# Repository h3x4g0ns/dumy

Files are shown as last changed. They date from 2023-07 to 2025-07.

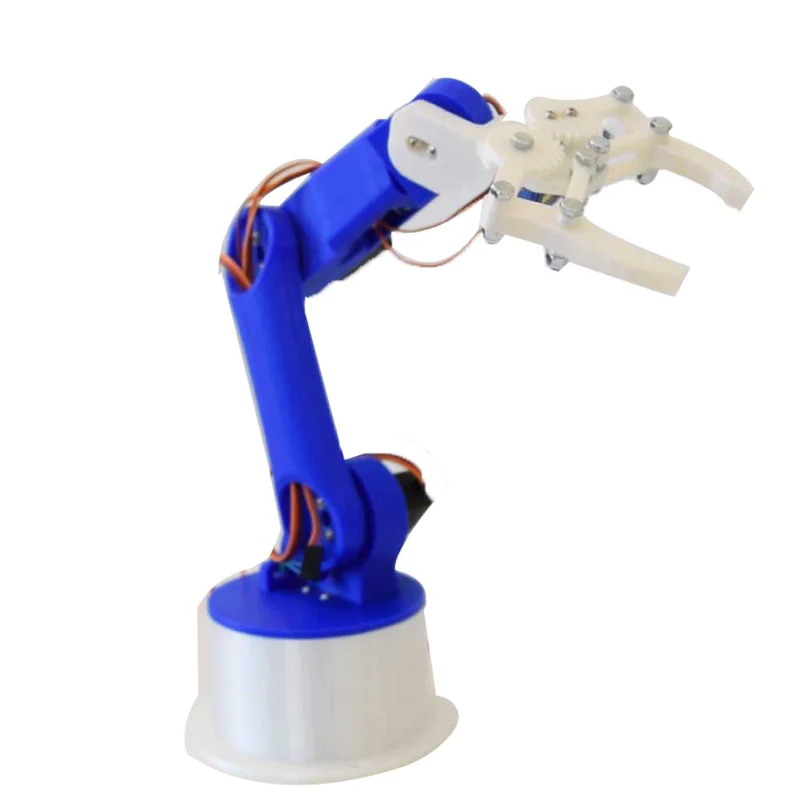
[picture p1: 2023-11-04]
robot_arm.webp

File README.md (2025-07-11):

# dumy

Control a 3/4 DOF robot arm to track a cat and constantly play laser pointer fetch with her

## design

- We will have the server code running on a Jetson that will capture the environment through a camera
- We want to perform our computations given the environment to control the world coordinates of the robot
- We will then want to pass in the new joint angles into a serial port on the RP2040 which is connected to the laser pointer arm
- This will move the robot arm accordingly so it's always stimulating the cat

**Vision Stack**

- We want to be able to track a bounding box over the moving cat
  - Use something like PyTorch YOLOv5 to get bounding box over entity identified as cat
    - We can use the center point of the cat
    - OR we can find point on bounding box closest to the laser pointer
- We want to constantly move the laser pointer such that it's moving away from the cat
- If we detect that cat has stopped chasing it, we should taunt the cat by moving the pointer in front of cat
- We can use the trajectory of the cat as a hueristic to determine where the cat will be headed

**Control Stack**

- We need calculate the world coordinate of the robot
  - Given goal coordinates we can solve analytical inverse kinematics to ascertain joint angles
- Pass in joint angles to RP2040 for control through serial communication
  - Server code runs on jetson and will connect to RP2040

## setup

First installing pico sdk.

```sh
cd ~
git clone -b master https://github.com/raspberrypi/pico-sdk.git
cd pico-sdk
git submodule update --init
```

Add following line to `.bashrc` or `.zshrc`.

```sh
export PICO_SDK=~/pico-sdk
```

Install toolchain for Pico projects

```sh
# DEBIAN
sudo apt update
sudo apt install cmake gcc-arm-none-eabi build-essential

# MACOS
# Install cmake
brew install cmake

# Install the arm eabi toolchain
brew tap ArmMbed/homebrew-formulae
brew install arm-none-eabi-gcc

# The equivalent to build-essential on linux, you probably already have this.
xcode-select --install
```

## notes

MiDaS Model: v3.0 DPTL-384
dpt_large_384

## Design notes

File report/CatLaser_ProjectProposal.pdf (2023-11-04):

Project Title: Dumy
Team: Ekansh Parag Agrawal , Anirudh Singh Chaudhary , Jayden Hilton EECS 149/249A Project Charter, Fall, 2023 Repo Link: h3x4g0ns/dumy (https://github.com/h3x4g0ns/dumy)

Project Goal:
The goal of the project is to automate playing a game of laser-fetch with a cat. We will utilize a 3-DOF robot arm with an attached laser. The computations will be done either by a headless Linux server computer or by an NVIDIA Jetson board.

Project Approach:
We will have the server code running on a [Jetson or Headless Linux server] that will process camera frames using a YOLOv5 model and monocular depth detection.With the monocular depth estimation we can use transformations to create a limited 3d world view. From the bounding box of the cat along with the calculated world position of the laser tip, we will then try and correct the position of the arm to the trajectory of the cat. We will solve an analytical inverse kinematic problem to understand where the robot arm must move in order to keep the laser pointer out of the cat’s reach. We will then want to pass in the new joint angles to the RP2040 through a serial connection from the Jetson. The RP2040 will then move the arm to the necessary world position from the joint angles. This will move the robot arm accordingly so it's always stimulating the cat.

Materials:
- RP2040
- NVIDIA Jetson
- 3d printed robot arm
- Headless Linux Server
- Laser pointer
- Servo motors
- Breadboard
- Jumper Cables
- Power Supply

Schedule:
Oct 23, 2023 : Complete Project Proposal
Nov 7, 2023: Milestone 1 Due
Hardware: Design, manufacture, and assembly robot arm
Robot Stack: Basic robot controls, being able to move and control the robot arm to go in the desired direction & orientation [Jaden]
Vision Stack: Be able to identify the cat and begin calculations for world position of the laser tip [Ekansh & Anirudh]
Nov 8-10, 2023: Milestone 1 Presentations
Nov TBD, 2023: Milestone 2 Due

This is more of the integration milestone where we should be able to move the robot arm to follow the cat. From there if we can do that then we will be able to move the laser pointer away from the cat as well. [Everyone together]
Nov - Dec, 2023: Milestone 2 Meetings
December 13, 2023: Project Demo/Poster
December 14, 2023: Peer Evals and Project Report Due

Risk and Feasibility:

Risks:
- Optimizing computer vision/latencies
- Possible hardware failures with servos and 3d printed parts.
- Stretch goals may not be feasible in allotted time
- When dealing with image <-> camera <-> world transformation there’s a lot of trial and error that goes into calibrations, projections, and transformations

Feasibility:
We believe that the project is entirely feasible, most of the resources required are already in hand, and the boilerplate code is in progress. The most obvious risks are with the vision stack, as that comprises most of the risk. There is no physical risk except for an uncontrolled robot swing but we will take necessary precautions to make sure that we are a safe distance away when dealing with the robot arm.

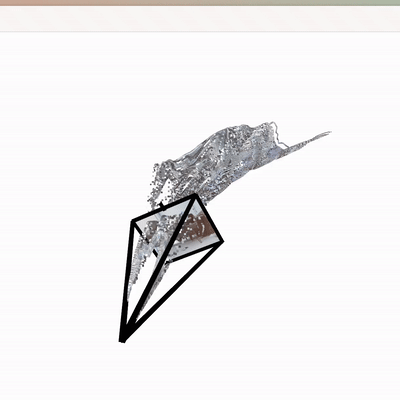
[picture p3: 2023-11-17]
report/voxel_view.gif

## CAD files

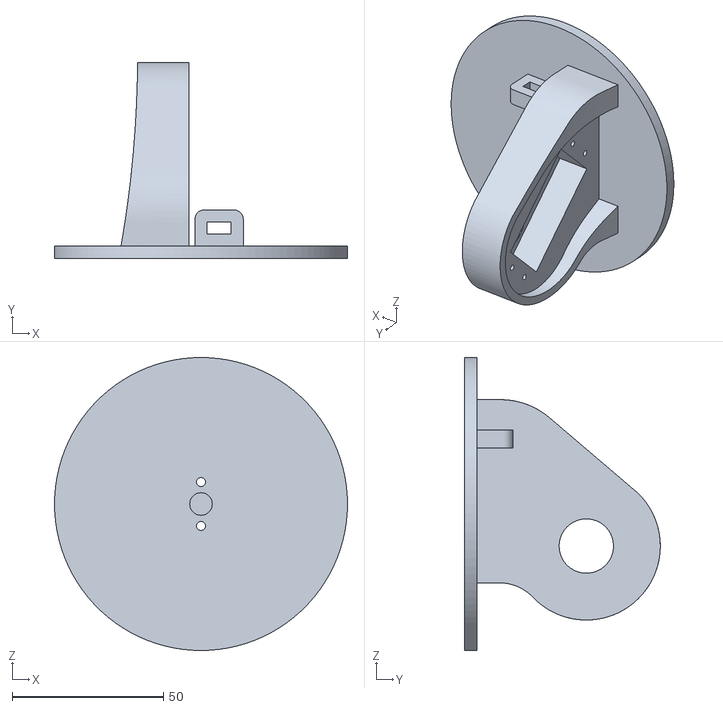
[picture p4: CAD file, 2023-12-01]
stl/Adjusted_WaistJoint.stl
97.0 x 64.8 x 97.0

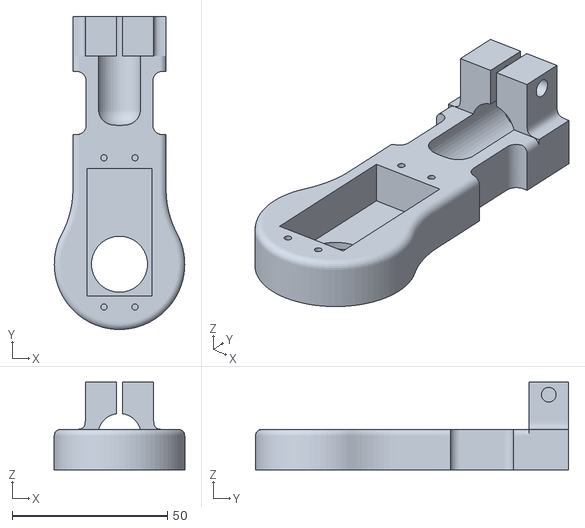
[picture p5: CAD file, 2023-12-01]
stl/Lightweight_Arm2_LaserClamp_v3.stl
42.0 x 100.7 x 28.2

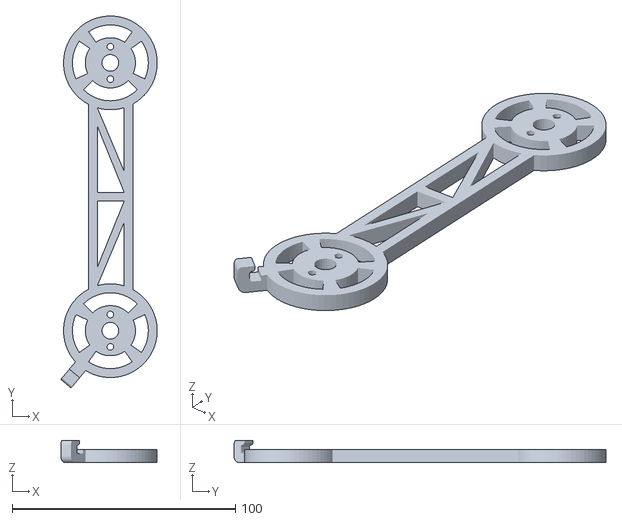
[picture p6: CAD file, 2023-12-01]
stl/Lightweight_Arm1.stl
43.2 x 166.7 x 10.0

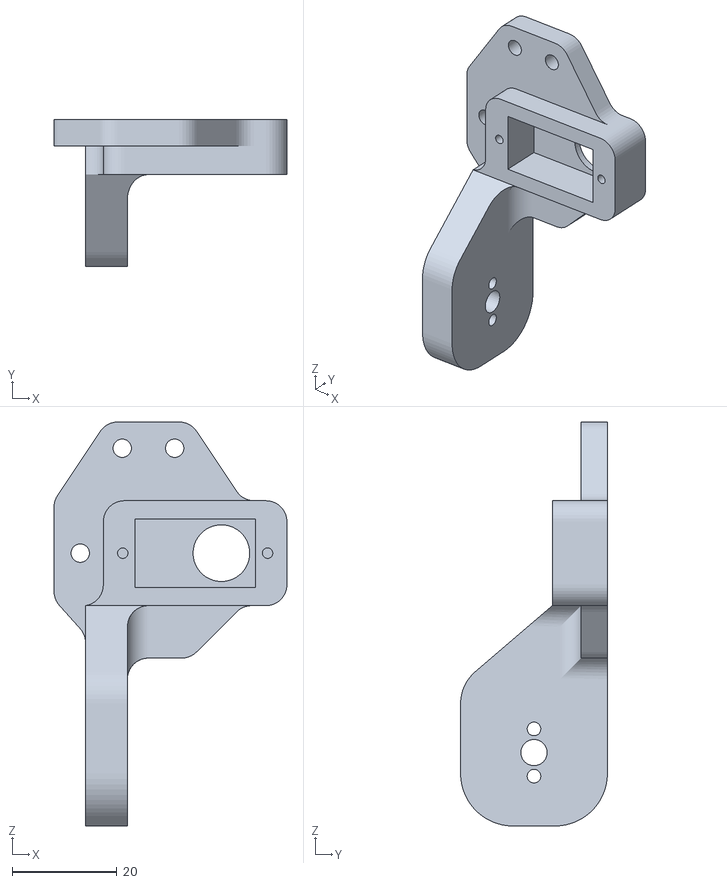
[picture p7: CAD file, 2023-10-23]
stl/Gripper base.stl
44.4 x 28.0 x 77.0

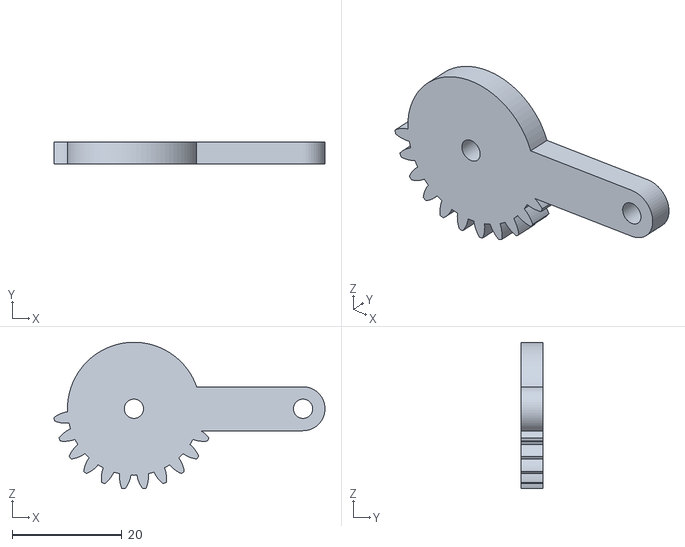
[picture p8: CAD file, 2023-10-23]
stl/gear1.stl
49.3 x 4.00 x 26.6

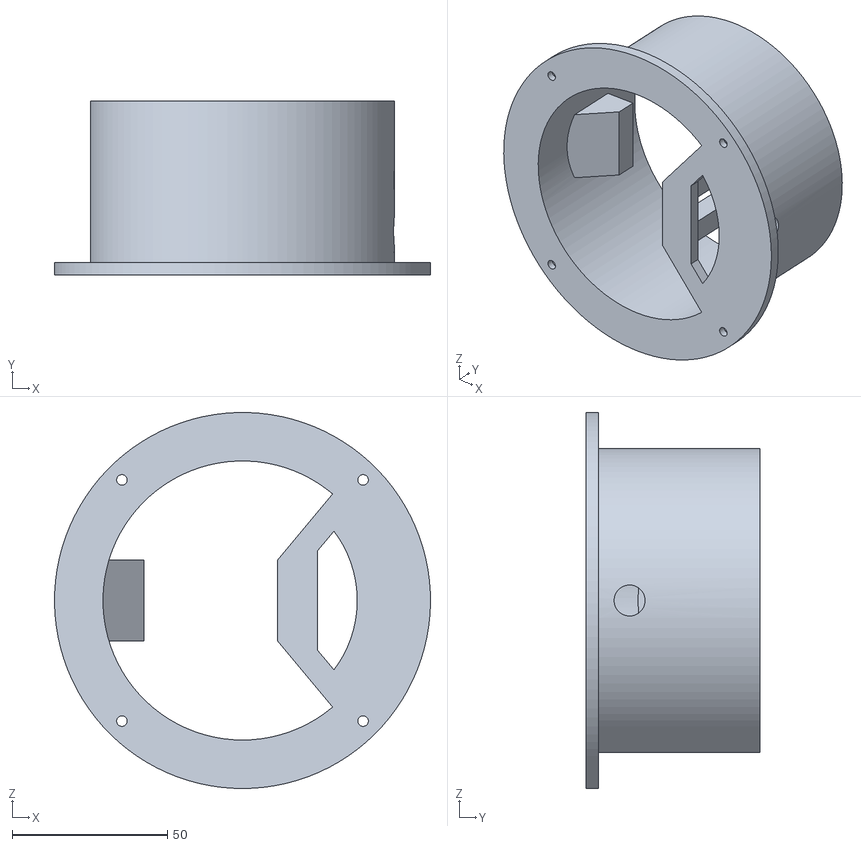
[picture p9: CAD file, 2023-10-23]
stl/Base.stl
121.2 x 56.0 x 121.2

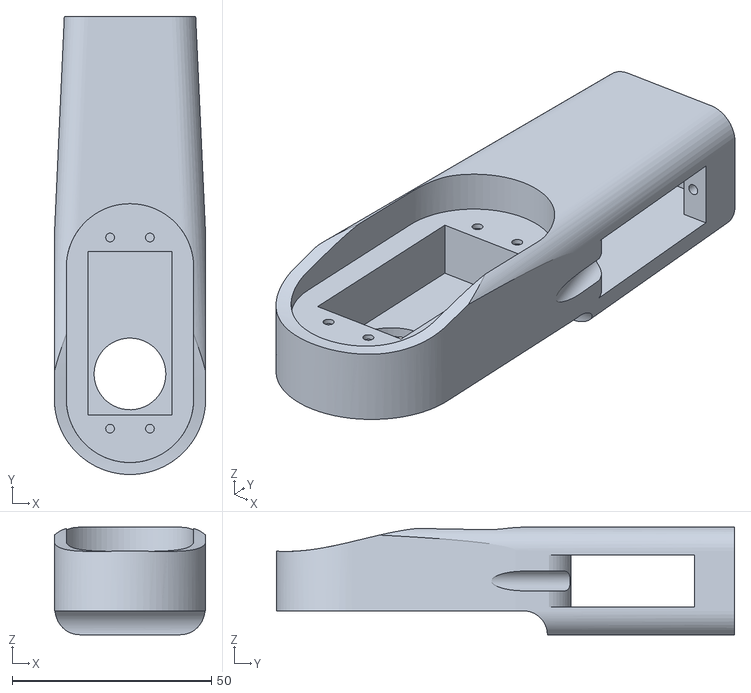
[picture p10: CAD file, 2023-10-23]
stl/Arm 02 v3.stl
38.0 x 115.0 x 27.0

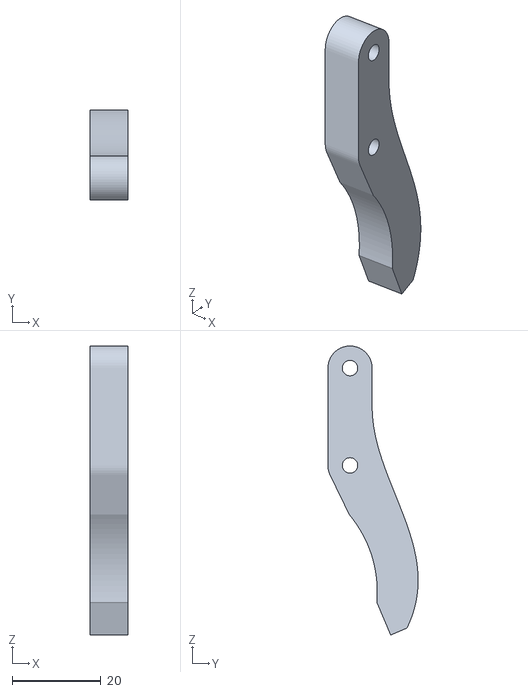
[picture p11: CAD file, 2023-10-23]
stl/Gripper 1.stl
8.50 x 20.4 x 65.3

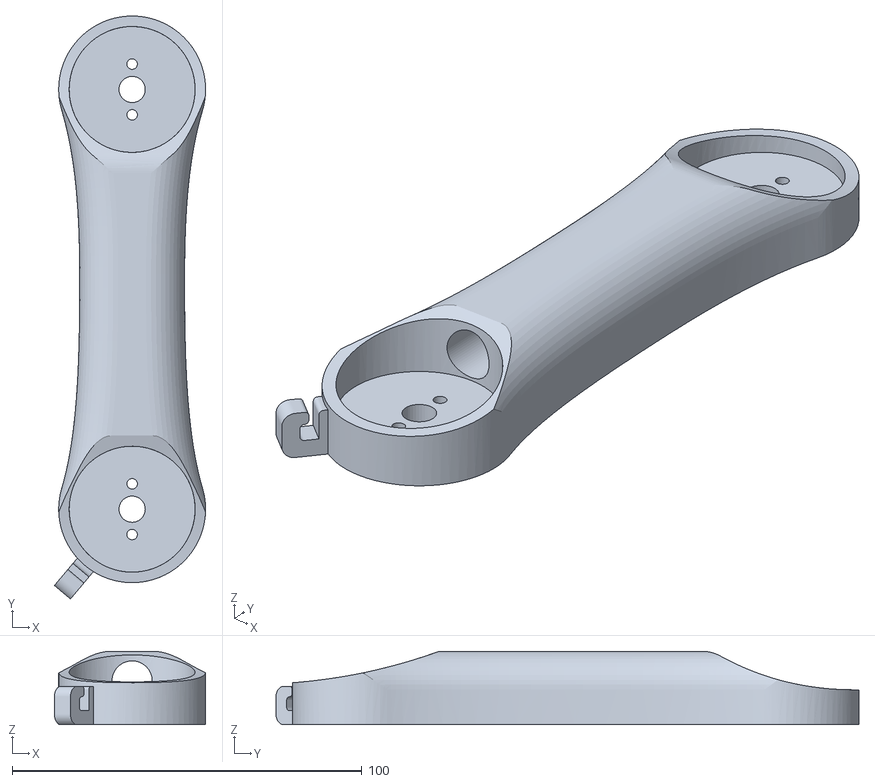
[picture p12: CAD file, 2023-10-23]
stl/Arm 01.stl
43.2 x 166.7 x 21.0

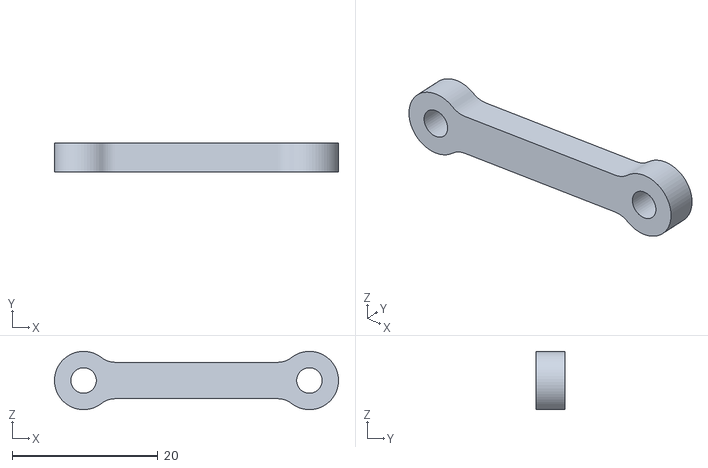
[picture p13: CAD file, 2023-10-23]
stl/grip link 1.stl
39.0 x 4.00 x 8.00

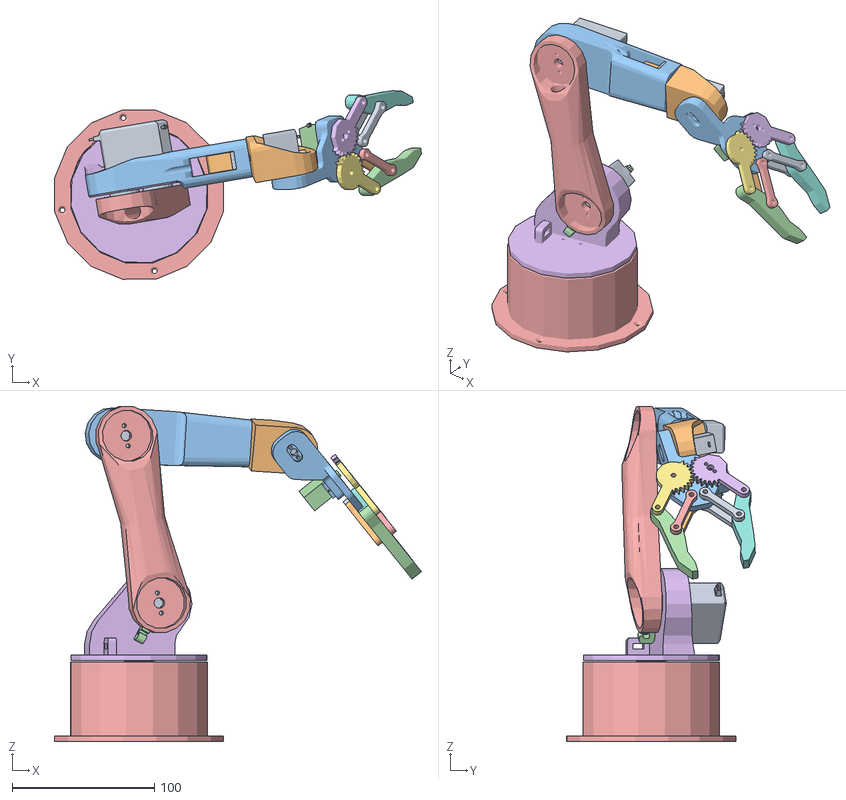
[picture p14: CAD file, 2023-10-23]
stl/Robotic Arm 3D Model.stl
258.2 x 132.6 x 235.7
Boss-Extrude2 x 2
Cut-Extrude2 x 4
Cut-Extrude1 x 4
Boss-Extrude5 x 3
Boss-Extrude7[1] x 3
Boss-Extrude7[2] x 3
Boss-Extrude7[3] x 3
Boss-Extrude12[1] x 3
Boss-Extrude12[2] x 3
Boss-Extrude12[3] x 3
Cut-Extrude7
Cut-Extrude17
CSK#for#M3#Countersunk#Flat#Head#Screw1

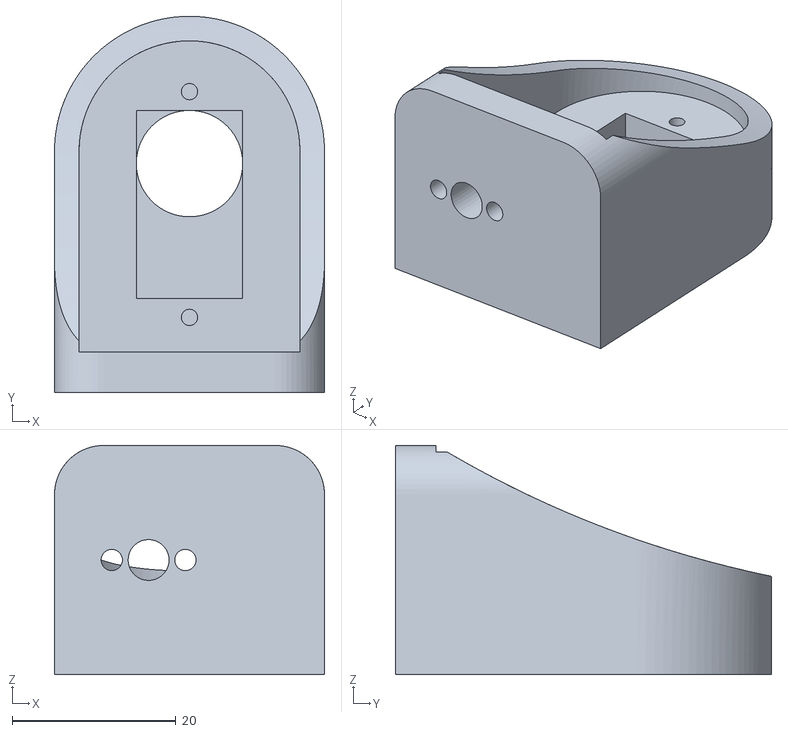
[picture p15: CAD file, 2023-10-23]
stl/Arm 03.stl
33.0 x 46.0 x 28.0

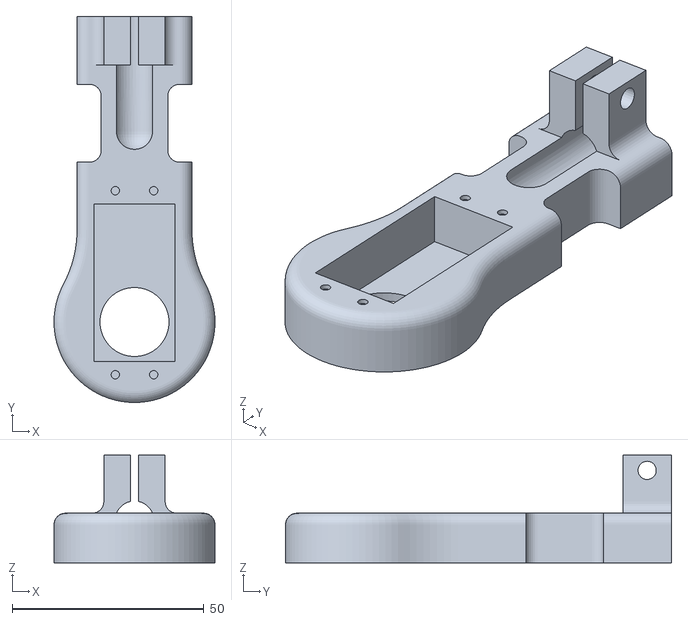
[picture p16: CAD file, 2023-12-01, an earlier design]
stl/Lightweight_Arm2_LaserClamp.stl
42.0 x 100.7 x 28.2

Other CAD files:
stl/Waist.stl
stl/gear2.stl
stl/Lightweight_Arm2_LaserClamp_v2.stl

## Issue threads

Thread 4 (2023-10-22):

depth to world

h3x4g0ns, 2023-10-22:
Now that we have the depth output from the world, we need to use it a heuristic to construct a 3d world view. This should be relatively trivial since the depth is returned as a float from the matrix. Think about this as lidar reconstruction with monocular depth estimation. Look at some of Anjoo;s work with Nerfs, although i doubt we will need anything as complicated as that. I will be completely honest I don't think this has to be extremely accurate so feel free to use whatever transformation mechanism you want.

TODO:
- [ ] make a `camera.py` file in the `lib` folder and write the starter code there

h3x4g0ns, 2023-11-18:
#7 finished

Closed 2023-11-18.

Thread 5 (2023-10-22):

serial controller for dumy

h3x4g0ns, 2023-10-22:
We want to be able to send joint angles from the IK that was solved in `lib/robot.py`. As a refresher, we pass in world coordinates and determine the required joint angles to allow the actuators to reach that world coordinate. Implementations should involve controlling servos on Dumy through MicroPython or Arduino.

TODO
- [ ] validate that IK works from robot
- [ ] send and read serial communication
- [ ] translate joint angles into corresponding PWM signals
- [ ] see if we need a homing mechanism since it's unclear if the servos have encoders

Closed 2023-12-01.

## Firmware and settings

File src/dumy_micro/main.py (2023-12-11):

import _thread
from machine import Pin, UART, Servo, PWM
import time

# Constants
L1_PORT = 10
L2_PORT = 11
L3_PORT = 12
PIEZO_PIN = 13  # TODO: Replace with the actual pin number for the piezo buzzer
OFFSET = 90

# Global variables
piezo_flag = False
piezo_lock = _thread.allocate_lock()  # Create a lock for the piezo_flag variable

# Initialize Servo objects
l1 = Servo(Pin(L1_PORT))
l2 = Servo(Pin(L2_PORT))
l3 = Servo(Pin(L3_PORT))
piezo = PWM(Pin(PIEZO_PIN))

# Function to parse into from serial in
def to_int(src, size):
    try:
        return int(src[:size])
    except ValueError:
        return 0

# Servo control function
def servo_control():
    # Setup UART for serial communication
    uart = UART(1, baudrate=9600)

    terminated = False
    data = bytearray(16)
    i = 0

    while True:
        if uart.any():
            incoming = uart.read(1)
            if incoming == b'r':
                terminated = True
                i = 0
            else:
                data[i] = incoming[0]
                i += 1

        if terminated:
            data_str = data.decode('utf-8').split(',')
            angles = [to_int(data_str[0], 5) + OFFSET,
                      to_int(data_str[1], 5) + OFFSET,
                      to_int(data_str[2], 5) + OFFSET]

            if angles[0] == 0 and angles[1] == 0 and angles[2] == 0:
                # trigger piezo buzzer
                with piezo_lock:
                    piezo_flag = True
            else:
                l1.angle(angles[0])
                l2.angle(angles[1])
                l3.angle(angles[2])

            terminated = False

# Piezo buzzer control function
def piezo_control():
    while True:
        # check if the piezo buzzer is triggered
        if piezo_flag:
            for i in range(50):
                piezo.freq(1500)  # Set frequency (e.g., A4 note)
                piezo.duty(50)   # Set duty cycle (volume)
                time.sleep(0.2)  # Play for 0.2 seconds
                piezo.freq(1000)  
                piezo.duty(75)
                time.sleep(0.2)
                piezo.freq(1200)
                piezo.duty(60)
                time.sleep(0.2)
                piezo.duty(0)    # Turn off the buzzer
                time.sleep(0.5)  # Pause for 0.2 seconds

            # acquire lock and rezet flag
            with piezo_lock:
                piezo_flag = False

# Start the servo control thread on core 0
_thread.start_new_thread(servo_control, ())

# Start the piezo control thread on core 1
_thread.start_new_thread(piezo_control, ())

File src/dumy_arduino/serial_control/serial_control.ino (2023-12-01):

#include <Servo.h>
#include "servo_control.h"

#define L1_PORT 10
#define L2_PORT 11
#define L3_PORT 12
#define OFFSET 90.0

Servo l1;
Servo l2;
Servo l3;

int i = 0;
volatile char data[16];
volatile bool terminated;

float strlfcopy(const char *src, size_t size) {
    char dst[size];
    int i = 0;
    float res;
    int n = 1;
    if (src[0] == '-') {
        *src++;
        n = -1;
    }
    while (size > 1 && *src) {
        dst[i] = *src++;
        i++;
        size--;
    }
    res = atof(dst);
    //Serial.println(res);
    return res * n;
}

void setup() {
    Serial.begin(9600);
    l1.attach(L1_PORT);
    l2.attach(L2_PORT);
    l3.attach(L3_PORT);
    //Serial.println("init");
    l1.write(90);
    l2.write(90);
    l3.write(90);
    terminated = false;
    data[0] = '\0';
}

void loop() {
    //read in serial data until the terminating character
    if (Serial.available()>0) {
        char incoming = Serial.read();
        if (incoming == 'r') {
            terminated = true;
            i = 0;
        } else {
            data[i] = incoming;
            i++;
        }
    }

    if (terminated) {
        float angles[3];
        angles[0] = strlfcopy(strtok(data, ", "), 5) + OFFSET;
        angles[1] = strlfcopy(strtok(NULL, ", "), 5) + OFFSET;
        angles[2] = strlfcopy(strtok(NULL, ", "), 5) + OFFSET;
        Serial.println(angles[0]);
        l1.write(angles[0]);
        l2.write(angles[1]);
        l3.write(angles[2]);
        memset(data, 0, 16);
        terminated = false;
    }
}

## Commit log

2023-07-10 index finger tracking
2023-07-11 single joint follow
2023-10-03 better servo control **unfinished**
2023-10-23 added 3d printed parts
    [Arm 01.stl, Arm 02 v3.stl, Arm 03.stl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]
2023-11-17 3d world reconstruction (#7)
    * basic occupancy rendering
    * trying to render 3d voxels
    * finished img -> camera rendering
    * rendering fps boost
    * added framework for c2w
2023-12-01 reading serial communication from server (#6)
    * partially complete serial control code
    * minor change to serial_control
    * removed linked list
    * fixed serial_control
    * how do i use named methods in python lol
    * fixed overwrite and issue with negatives
    * wrong terminator
    * switching
    * main changes
    * initial move to world test, might need to add delays to let serial coms catch up
    * added stls for updated arm
    * adjusted stls
    * issue with serial coms again maybe?
    * radian to degrees conversion lol
    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
    [Lightweight_Arm1.stl, Lightweight_Arm2_LaserClamp.stl, Lightweight_Arm2_LaserClamp_v2.stl]
2023-12-01 basic control on thread 1
2023-12-01 fastener and size adjust for waist and arm 2
    [Adjusted_WaistJoint.stl, Lightweight_Arm2_LaserClamp_v3.stl]
